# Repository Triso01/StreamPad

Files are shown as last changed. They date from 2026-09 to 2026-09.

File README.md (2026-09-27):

The Case:


On the left the topplate and on the right the case.
You should print the TopPlate with 100% Gyroid infill.
The Case should be printed with 20%< Gyriod Infill.

The PCB:




The settings for the PCB should look like this: (You can change the color or surface finish!)


What is it made for?
I am a little streamer who needs a soundboard/"Streamdeck" and it is a good oportunity to get one "for free" :). 
I hope you all like the design (Its my first one in Fusion).

BOM:
HackPad Kit (You dont have a kit? You can find the components here: https://hackpad.hackclub.com/parts)
You also need 2x CD4051BM (these are Multiplexers)
!!The Case might change after I get the PCB!!

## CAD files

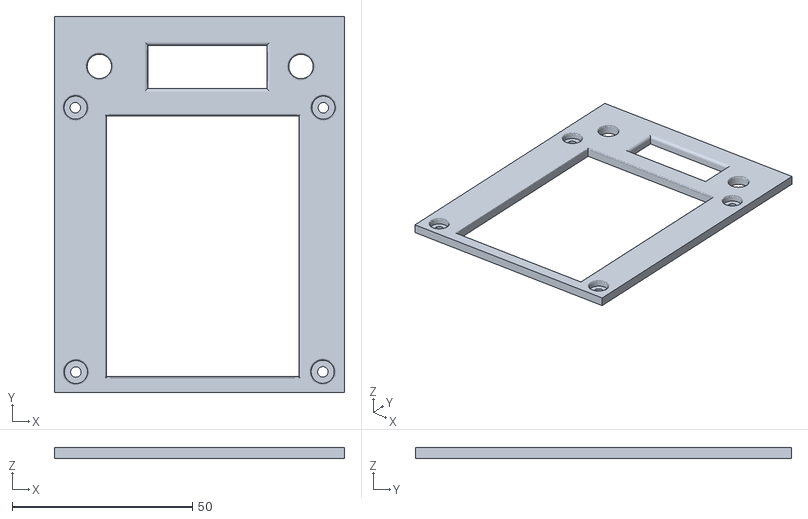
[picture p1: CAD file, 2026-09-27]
Case/StreamPad-TopPlate.stl
80.5 x 104.5 x 3.00

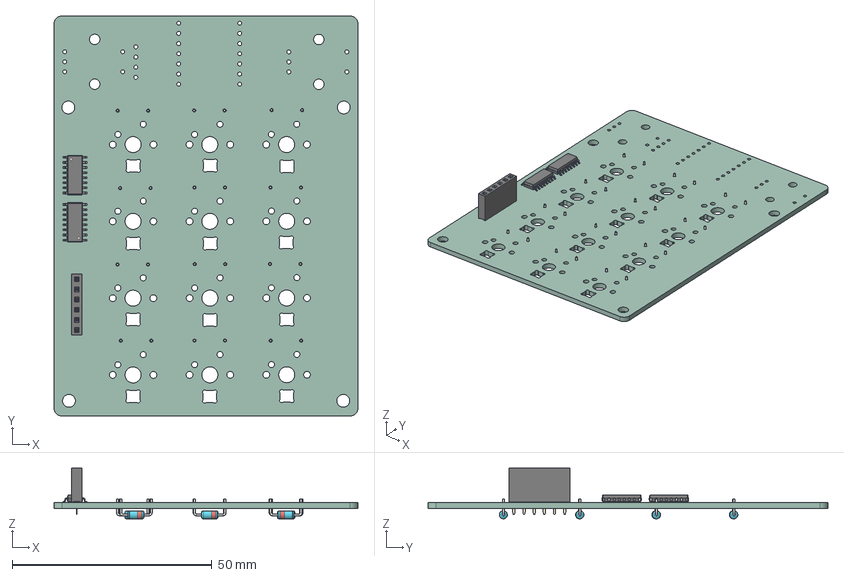
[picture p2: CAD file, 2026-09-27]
PCB/HackPad.step
76.0 x 100.0 x 12.7 mm
PinSocket_1x06_P2.54mm_Vertical
SOIC-16_3.9x9.9mm_P1.27mm x 2
D_DO-35_SOD27_P7.62mm_Horizontal x 12
Hac13B5_PCB

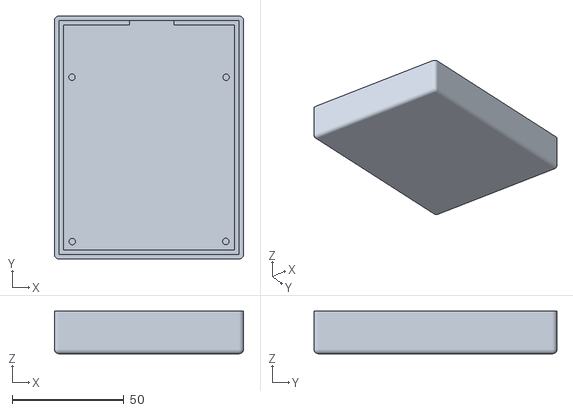
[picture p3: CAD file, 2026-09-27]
Case/StreamPad-Case.stl
84.5 x 108.5 x 19.0

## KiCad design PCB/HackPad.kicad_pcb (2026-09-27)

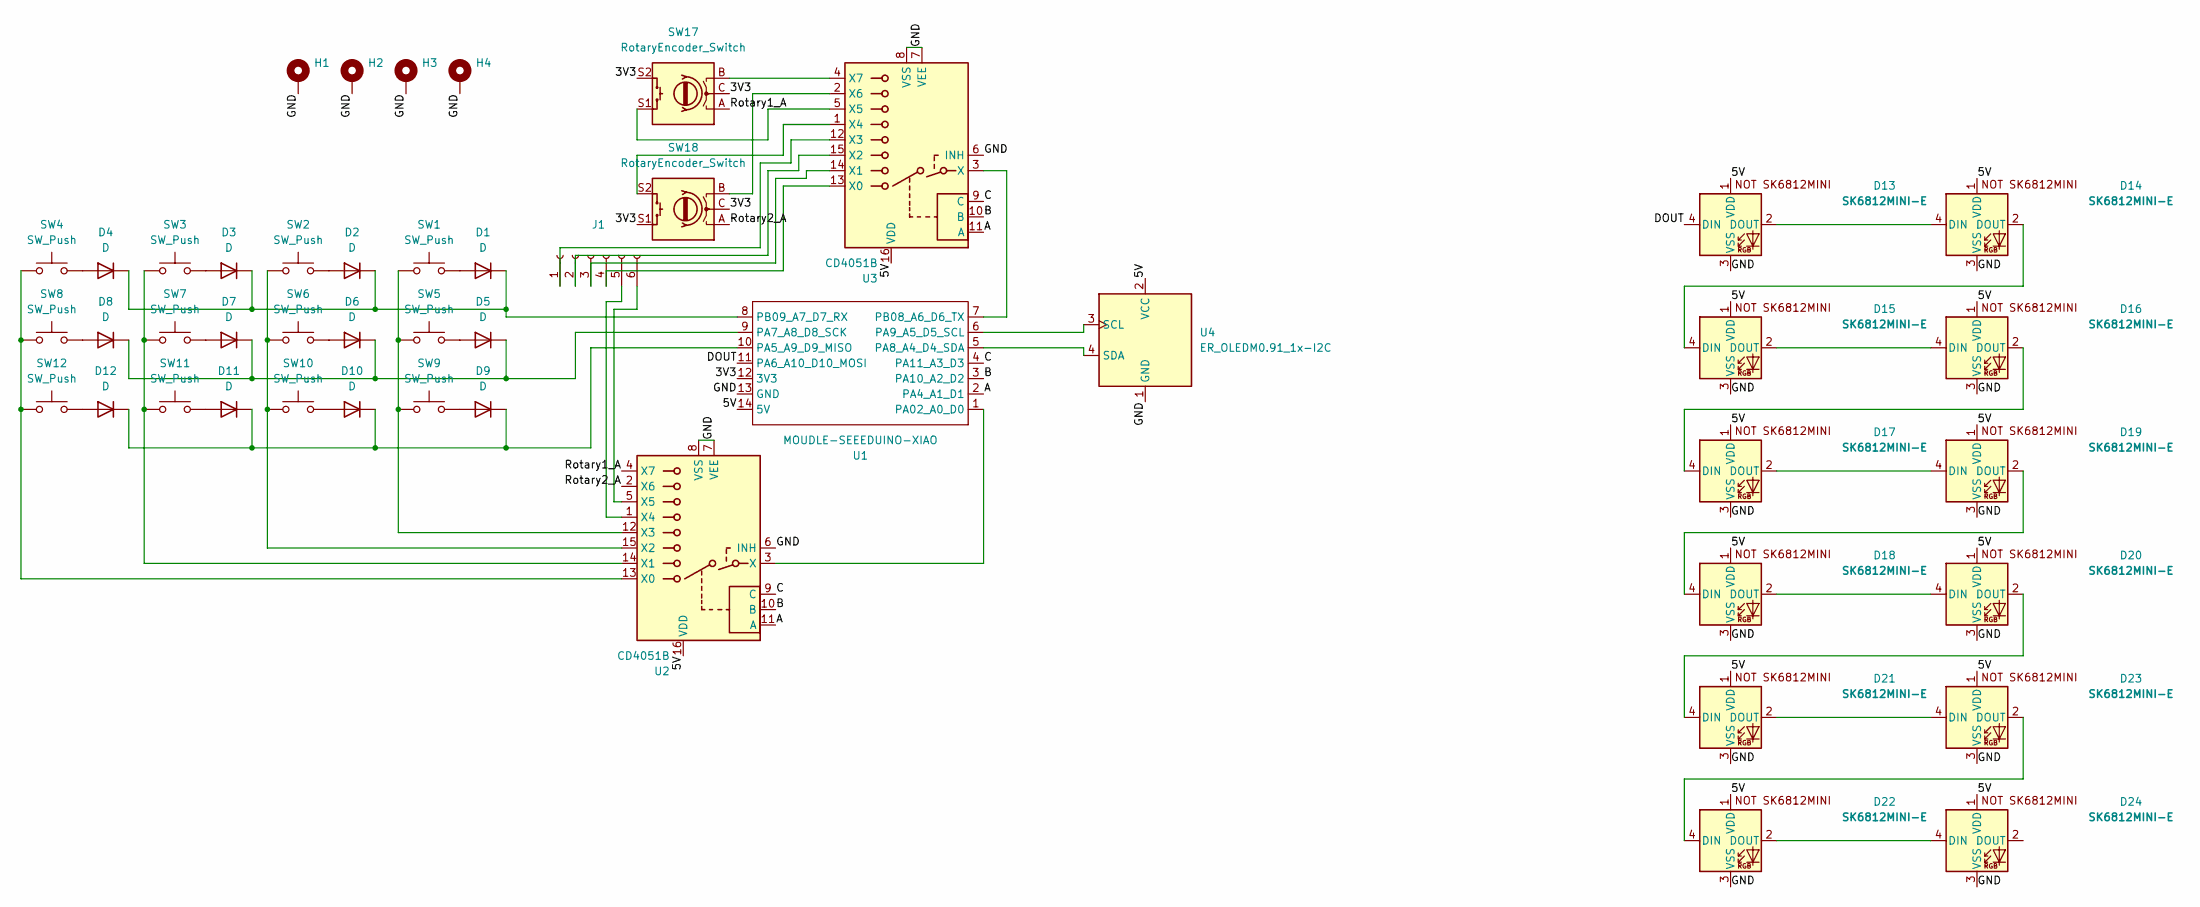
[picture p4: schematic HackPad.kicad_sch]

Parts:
D1, D2, D3, D4, D5, D6, D7, D8, D9, D10, D11, D12: D; D_DO-35_SOD27_P7.62mm_Horizontal
D13, D14, D15, D16, D17, D18, D19, D20, D21, D22, D23, D24: SK6812MINI-E; SK6812MINI-E_fixed
H1, H2, H3, H4: MountingHole_Pad; MountingHole_3.2mm_M3_DIN965_Pad
J1: Conn_01x06_Socket; PinSocket_1x06_P2.54mm_Vertical
SW1, SW2, SW3, SW4, SW5, SW6, SW7, SW8, SW9, SW10, SW11, SW12: SW_Push; SW_Cherry_MX_1.00u_PCB
SW17, SW18: RotaryEncoder_Switch; RotaryEncoder_Alps_EC11E-Switch_Vertical_H20mm_CircularMoun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
U1: MOUDLE-SEEEDUINO-XIAO; XIAO-Generic-Hybrid-14P-2.54-21X17.8MM
U2, U3: CD4051B; SOIC-16_3.9x9.9mm_P1.27mm
U4: ER_OLEDM0.91_1x-I2C

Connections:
/3V3: SW17.C, SW17.S2, SW18.C, SW18.S1, U1.12 (3V3)
/5V: D13.1 (VDD), D14.1 (VDD), D15.1 (VDD), D16.1 (VDD), D17.1 (VDD), D18.1 (VDD), D19.1 (VDD), D20.1 (VDD), D21.1 (VDD), D22.1 (VDD), D23.1 (VDD), D24.1 (VDD), U1.14 (5V), U2.16 (VDD), U3.16 (VDD), U4.2 (VCC)
/A: U1.2 (PA4_A1_D1), U2.11 (A), U3.11 (A)
/B: U1.3 (PA10_A2_D2), U2.10 (B), U3.10 (B)
/C: U1.4 (PA11_A3_D3), U2.9 (C), U3.9 (C)
/DOUT: D13.4 (DIN), U1.11 (PA6_A10_D10_MOSI)
/GND: D13.3 (VSS), D14.3 (VSS), D15.3 (VSS), D16.3 (VSS), D17.3 (VSS), D18.3 (VSS), D19.3 (VSS), D20.3 (VSS), D21.3 (VSS), D22.3 (VSS), D23.3 (VSS), D24.3 (VSS), H1.1 (1_1), H2.1 (1_1), H3.1 (1_1), H4.1 (1_1), U1.13 (GND), U2.6 (INH), U2.7 (VEE), U2.8 (VSS), U3.6 (INH), U3.7 (VEE), U3.8 (VSS), U4.1 (GND)
/Rotary1_A: SW17.A, U2.4 (X7)
/Rotary2_A: SW18.A, U2.2 (X6)
unnamed: D1.2 (A), SW1.1
unnamed: D1.1 (K), D2.1 (K), D3.1 (K), D4.1 (K), U1.8 (PB09_A7_D7_RX)
unnamed: D2.2 (A), SW2.1
unnamed: D3.2 (A), SW3.1
unnamed: D4.2 (A), SW4.1
unnamed: D5.2 (A), SW5.1
unnamed: D5.1 (K), D6.1 (K), D7.1 (K), D8.1 (K), U1.9 (PA7_A8_D8_SCK)
unnamed: D6.2 (A), SW6.1
unnamed: D7.2 (A), SW7.1
unnamed: D8.2 (A), SW8.1
unnamed: D9.2 (A), SW9.1
unnamed: D10.2 (A), SW10.1
unnamed: D9.1 (K), D10.1 (K), D11.1 (K), D12.1 (K), U1.10 (PA5_A9_D9_MISO)
unnamed: D11.2 (A), SW11.1
unnamed: D12.2 (A), SW12.1
unnamed: D13.2 (DOUT), D14.4 (DIN)
unnamed: D14.2 (DOUT), D15.4 (DIN)
unnamed: D15.2 (DOUT), D16.4 (DIN)
unnamed: D16.2 (DOUT), D17.4 (DIN)
unnamed: D17.2 (DOUT), D19.4 (DIN)
unnamed: D18.4 (DIN), D19.2 (DOUT)
unnamed: D18.2 (DOUT), D20.4 (DIN)
unnamed: D20.2 (DOUT), D21.4 (DIN)
unnamed: D21.2 (DOUT), D23.4 (DIN)
unnamed: D22.4 (DIN), D23.2 (DOUT)
unnamed: D22.2 (DOUT), D24.4 (DIN)
unnamed: J1.1, U3.12 (X3)
unnamed: J1.2, U3.15 (X2)
unnamed: J1.3, U3.14 (X1)
unnamed: J1.4, U3.13 (X0)
unnamed: J1.5, U2.1 (X4)
unnamed: J1.6, U2.5 (X5)
unnamed: U1.1 (PA02_A0_D0), U2.3 (X)
unnamed: U1.5 (PA8_A4_D4_SDA), U4.4 (SDA)
unnamed: U1.6 (PA9_A5_D5_SCL), U4.3 (SCL)
unnamed: U1.7 (PB08_A6_D6_TX), U3.3 (X)
unnamed: SW4.2, SW8.2, SW12.2, U2.13 (X0)
unnamed: SW3.2, SW7.2, SW11.2, U2.14 (X1)
unnamed: SW2.2, SW6.2, SW10.2, U2.15 (X2)
unnamed: SW1.2, SW5.2, SW9.2, U2.12 (X3)
unnamed: SW18.S2, U3.1 (X4)
unnamed: SW17.S1, U3.5 (X5)
unnamed: SW18.B, U3.2 (X6)
unnamed: SW17.B, U3.4 (X7)

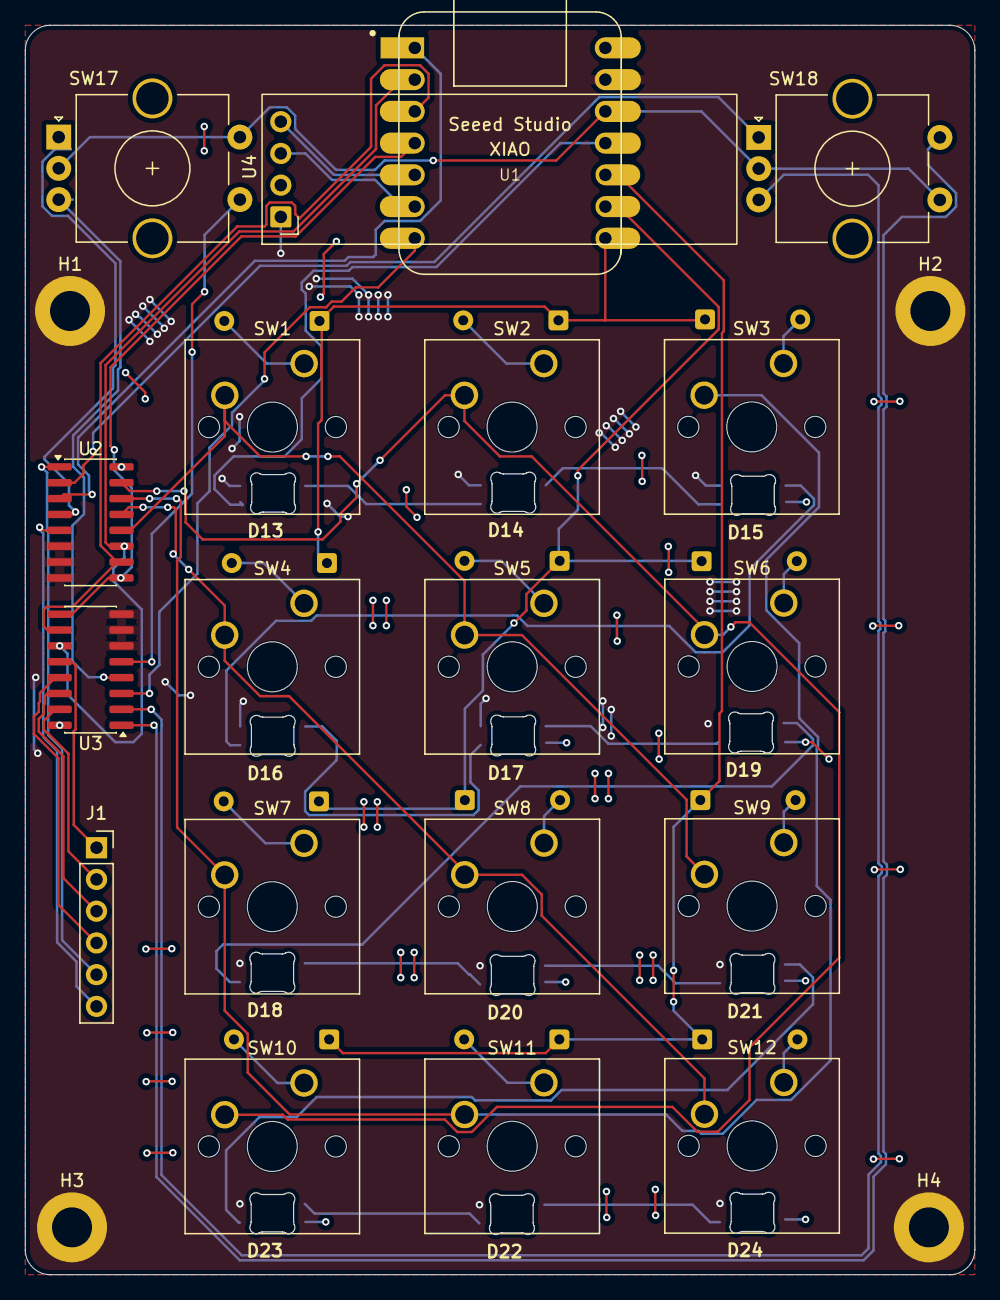
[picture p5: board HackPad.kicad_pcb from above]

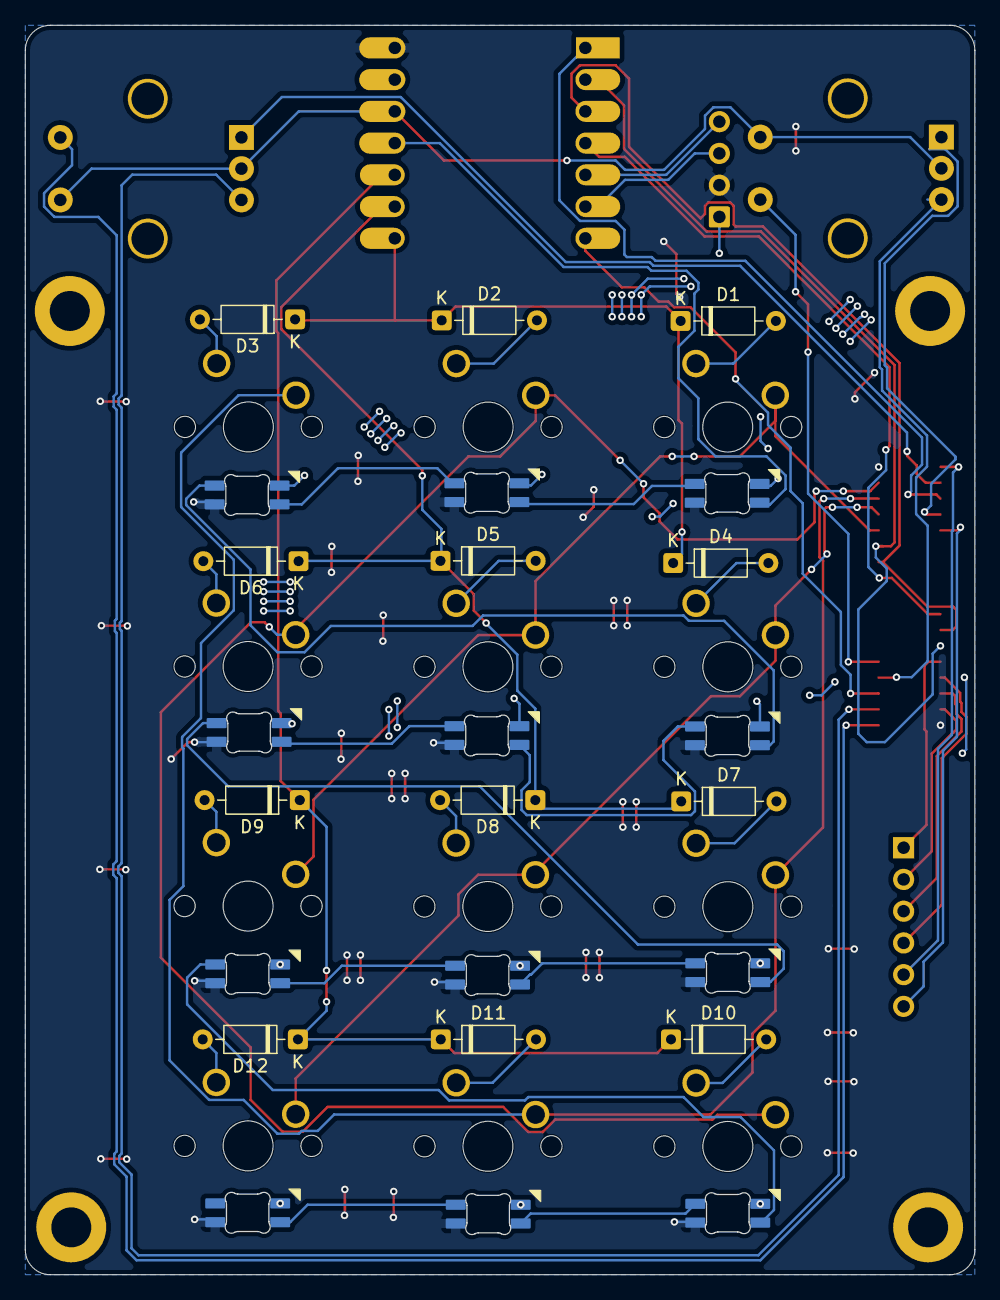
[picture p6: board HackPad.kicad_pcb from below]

Board: 2 copper layers, 76.0 x 100.0 mm, 47 parts (12 on the bottom side), 53 nets.

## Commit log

2026-09-27 Update README with project details and images
    Added images and details about the case and PCB for the StreamPad project.
2026-09-27 Here are the PCBs :)
2026-09-27 Add case.txt with initial content
2026-09-27 Update README with printing instructions and PCB settings
    Added printing instructions for TopPlate and Case, and included PCB settings.
2026-09-27 Update README with BOM and new image
    Added BOM section and additional image to README.
